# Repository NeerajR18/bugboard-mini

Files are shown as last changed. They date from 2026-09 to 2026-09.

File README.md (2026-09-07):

# bugboard-mini
Small Size development board based on the STM32G431KBT6

## Features
- Small PCB, 20 mm x 25 mm
- Debug headers included
- Supports USART

## PCB

#### Schematic


#### PCB

- PCB front



- PCB back



Made fully in KiCad.

## Bill of Materials

| MPN | Quantity | Unit Price (USD) | Ext. Price (USD) | Link |
|---|---:|---:|---:|---|
| STM32G431KBT6 | 1 | $7.03 | $7.03 | [LionCircuits](https://www.lioncircuits.com/parts/STM32G431KBT6) |
| RC0402FR-1010KL | 100 | $0.0037 | $0.37 | [Robu](https://robu.in/product/rc0402fr-1010kl-yageo-0-063w-thick-film-resistors-%c2%b1100ppm-%e2%84%83-%c2%b11-10k%cf%89-0402-chip-resistor-surface-mount-rohs/) |
| RC0402FR-075K1L | 100 | $0.002 | $0.20 | [Robu](https://robu.in/product/rc0402fr-075k1l-yageo-res-thick-film-0402-5-1k-ohm-1-0-063w1-16w-%c2%b1100ppm-c-pad-smd-t-r/) |
| XC6206P182MR | 5 | $0.037 | $0.185 | [Robu](https://robu.in/product/xc6206p182mr-twgmc-70db1khz-300ma-fixed-1-8v-positive-electrode-6v-sot-23-voltage-regulators-linear-low-drop-out-ldo-regulators-rohs/) |
| TCC0402X5R104K500AT | 100 | $0.0025 | $0.25 | [Robu](https://robu.in/product/tcc0402x5r104k500at-cctc-smt-ceramic-capacitors-0402-x5r-104k100nf%c2%b110-rated-voltage50v-thickness0-50mm-tape/) |
| PRTR5V0U2X | 5 | $0.095 | $0.475 | [Robu](https://robu.in/product/prtr5v0u2x215-nexperia-prtr5v0u2x215-esd-protection-device-tvs-7-5-v-sot-143b-4-pins-5-5-v-prtr5/) |
| TYPE-C-31-M-12 | 2 | $0.40 | $0.80 | [Robu](https://robu.in/product/type-c-31-m-12-hroparts-5a-1-16p-female-type-c-smd-usb-connectors-rohs/) |
| SMD0603P050TF | 5 | $0.13 | $0.65 | [Robu](https://robu.in/product/smd0603p050tf-pttcpolytronics-tech-6v-40a-500ma-1a-0603-resettable-rohs/) |
| TS-1088-AR02016 | 5 | $0.029 | $0.145 | [Robu](https://robu.in/product/1-month-warranty-470/) |
| CC0402MRX5R5BB106 | 10 | $0.048 | $0.48 | [Robu](https://robu.in/product/cc0402mrx5r5bb106-yageo-cap-smd-mlcc-10-%c2%b5f-6-3-v-0402-1005-metric-20-x5r-cc-series/) |
| PCB from ROBU | 5 | $1.90 | $9.52 | [Robu](https://robu.in/product/online-pcb-manufacturing-service/) |
| Shipping Charges | - | $5.00 | $5.00 | - |
| **Total** | | **$14.6772** | | |

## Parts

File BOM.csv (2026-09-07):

MPN | Quantity | Unit Price(USD) | Ext. Price(USD) | Link
STM32G431KBT6 | 1 | 7.03 | 7.03 | https://www.lioncircuits.com/parts/STM32G431KBT6
RC0402FR-1010KL | 100 | 0.0037 | 0.37 | https://robu.in/product/rc0402fr-1010kl-yageo-0-063w-thick-film-resistors-%c2%b1100ppm-%e2%84%83-%c2%b11-10k%cf%89-0402-chip-resistor-surface-mount-rohs/
RC0402FR-075K1L | 100 | 0.002 | 0.2 | https://robu.in/product/rc0402fr-075k1l-yageo-res-thick-film-0402-5-1k-ohm-1-0-063w1-16w-%c2%b1100ppm-c-pad-smd-t-r/
XC6206P182MR | 5 | 0.037 | 0.185 | https://robu.in/product/xc6206p182mr-twgmc-70db1khz-300ma-fixed-1-8v-positive-electrode-6v-sot-23-voltage-regulators-linear-low-drop-out-ldo-regulators-rohs/
TCC0402X5R104K500AT | 100 | 0.0025 | 0.25 | https://robu.in/product/tcc0402x5r104k500at-cctc-smt-ceramic-capacitors-0402-x5r-104k100nf%c2%b110-rated-voltage50v-thickness0-50mm-tape/
PRTR5V0U2X | 5 | 0.095 | 0.475 | https://robu.in/product/prtr5v0u2x215-nexperia-prtr5v0u2x215-esd-protection-device-tvs-7-5-v-sot-143b-4-pins-5-5-v-prtr5/
TYPE-C-31-M-12 | 2 | 0.4 | 0.8 | https://robu.in/product/type-c-31-m-12-hroparts-5a-1-16p-female-type-c-smd-usb-connectors-rohs/
SMD0603P050TF | 5 | 0.13 | 0.65 | https://robu.in/product/smd0603p050tf-pttcpolytronics-tech-6v-40a-500ma-1a-0603-resettable-rohs/
TS-1088-AR02016 | 5 | 0.029 | 0.145 | https://robu.in/product/1-month-warranty-470/
CC0402MRX5R5BB106 | 10 | 0.048 | 0.48 | https://robu.in/product/cc0402mrx5r5bb106-yageo-cap-smd-mlcc-10-%c2%b5f-6-3-v-0402-1005-metric-20-x5r-cc-series/
PCB from ROBU | 5 | 1.9 | 9.52 | https://robu.in/product/online-pcb-manufacturing-service/
Shipping Charges | - | 5 | 5
Total |  | 14.6772

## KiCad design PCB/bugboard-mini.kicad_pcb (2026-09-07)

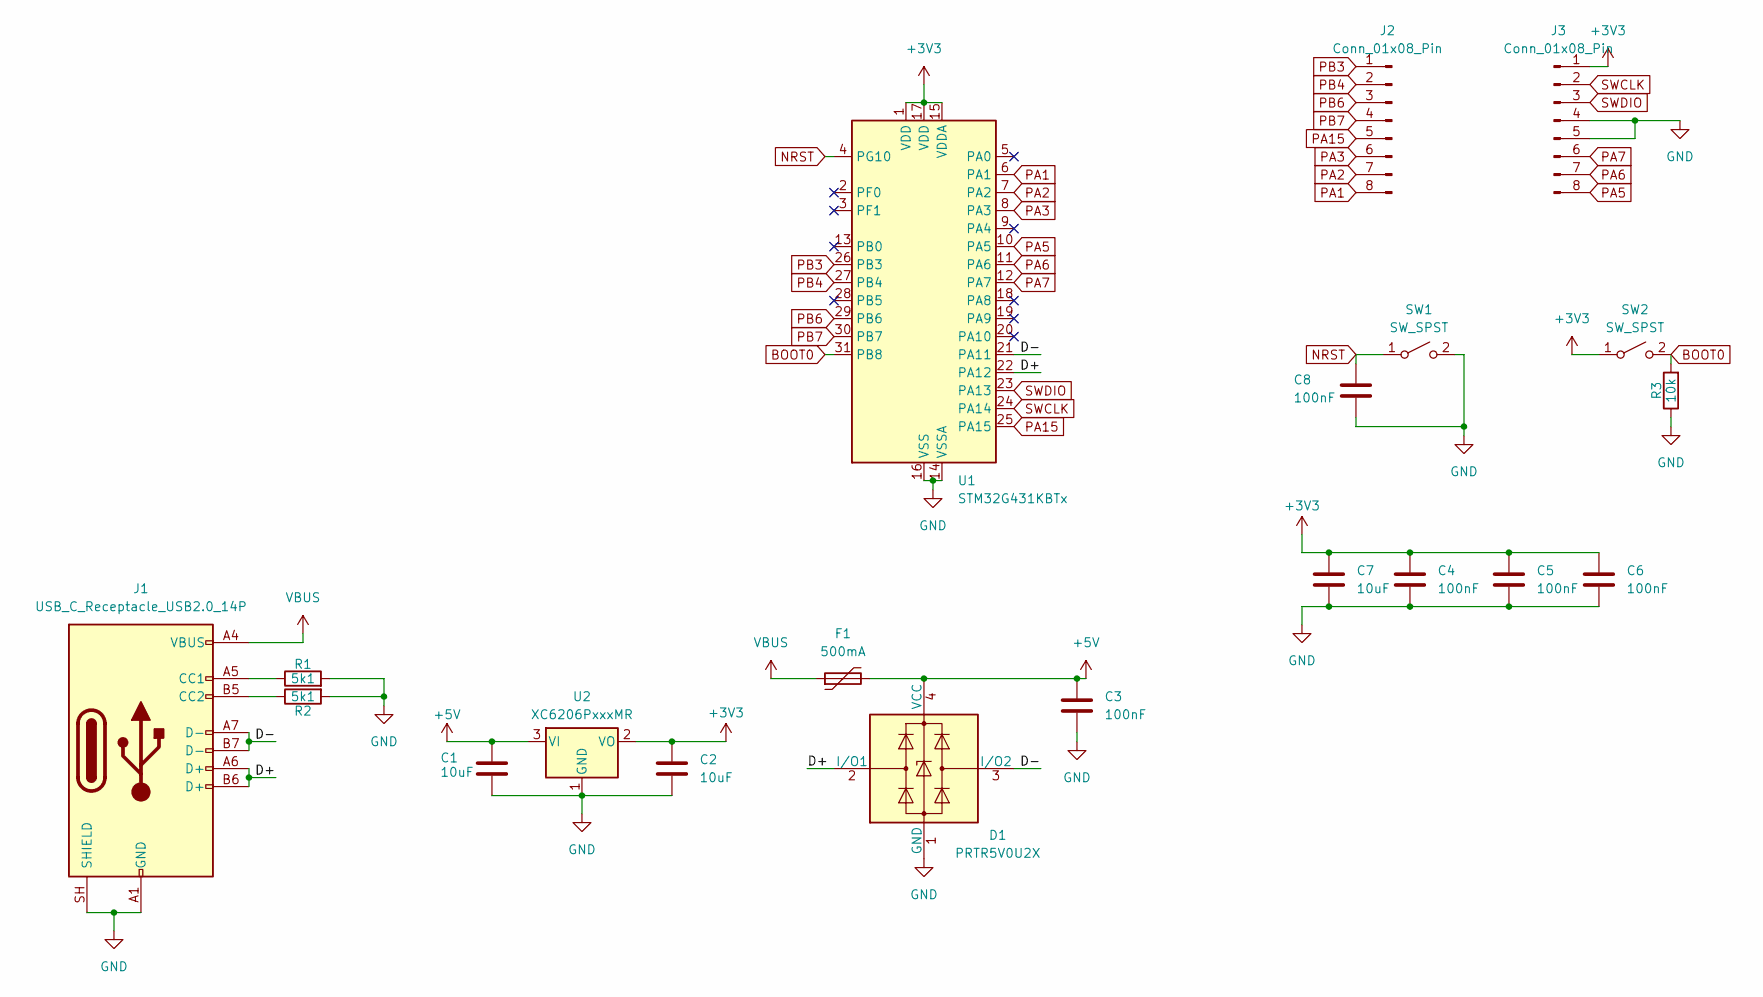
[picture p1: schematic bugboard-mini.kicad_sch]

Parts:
C1, C2, C7: 10uF; C_0402_1005Metric
C3, C4, C5, C6, C8: 100nF; C_0402_1005Metric
D1: PRTR5V0U2X; SOT-143
F1: 500mA; Fuse_0603_1608Metric
J1: USB_C_Receptacle_USB2.0_14P; USB_C_Receptacle_HRO_TYPE-C-31-M-12
J2, J3: Conn_01x08_Pin; PinHeader_1x08_P2.54mm_Vertical
R1, R2: 5k1; C_0402_1005Metric
R3: 10k; C_0402_1005Metric
SW1, SW2: SW_SPST; SW_SPST_TS-1088-xR020
U1: STM32G431KBTx; LQFP-32_7x7mm_P0.8mm
U2: XC6206PxxxMR; SOT-23-3

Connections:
+3V3: C2.1, C4.1, C5.1, C6.1, C7.1, J3.1, SW2.1 (A), U1.1 (VDD), U1.15 (VDDA), U1.17 (VDD), U2.2 (VO)
+5V: C1.1, C3.1, D1.4 (VCC), F1.2, U2.3 (VI)
/D+: D1.2 (I/O1), J1.A6 (D+), J1.B6 (D+), U1.22 (PA12)
/D-: D1.3 (I/O2), J1.A7 (D-), J1.B7 (D-), U1.21 (PA11)
BOOT0: R3.2, SW2.2 (B), U1.31 (PB8)
GND: C1.2, C2.2, C3.2, C4.2, C5.2, C6.2, C7.2, C8.2, D1.1 (GND), J1.A1 (GND), J1.A12 (GND), J1.B1 (GND), J1.B12 (GND), J1.SH (SHIELD), J3.4, J3.5, R1.2, R2.2, R3.1, SW1.2 (B), U1.14 (VSSA), U1.16 (VSS), U1.32 (VSS), U2.1 (GND)
NRST: C8.1, SW1.1 (A), U1.4 (PG10)
unnamed: J1.A5 (CC1), R1.1
unnamed: J1.B5 (CC2), R2.1
PA1: J2.8, U1.6 (PA1)
PA2: J2.7, U1.7 (PA2)
PA3: J2.6, U1.8 (PA3)
PA5: J3.8, U1.10 (PA5)
PA6: J3.7, U1.11 (PA6)
PA7: J3.6, U1.12 (PA7)
PA15: J2.5, U1.25 (PA15)
PB3: J2.1, U1.26 (PB3)
PB4: J2.2, U1.27 (PB4)
PB6: J2.3, U1.29 (PB6)
PB7: J2.4, U1.30 (PB7)
SWCLK: J3.2, U1.24 (PA14)
SWDIO: J3.3, U1.23 (PA13)
VBUS: F1.1, J1.A4 (VBUS), J1.A9 (VBUS), J1.B4 (VBUS), J1.B9 (VBUS)

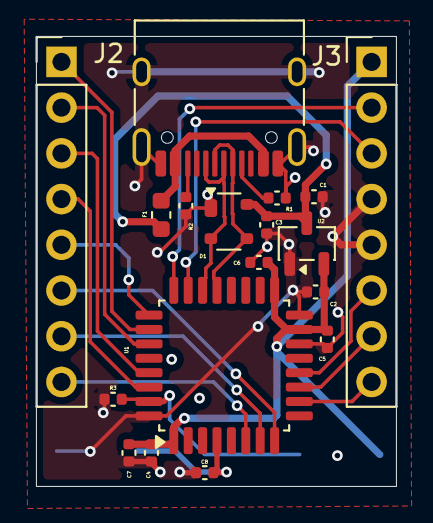
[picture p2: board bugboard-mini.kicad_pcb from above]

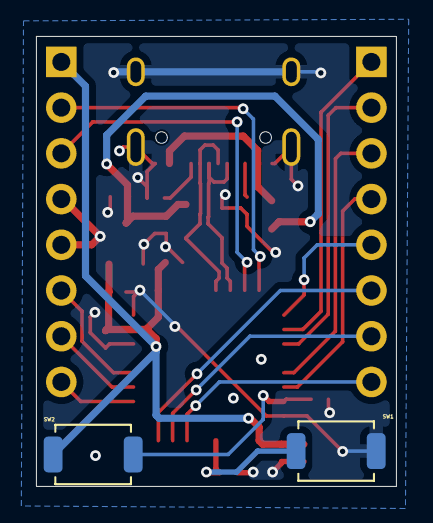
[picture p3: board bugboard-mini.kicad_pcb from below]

Board: 2 copper layers, 20.0 x 25.0 mm, 20 parts (2 on the bottom side), 23 nets.

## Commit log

2026-09-07 Added PCB files
    [bugboard-mini.kicad_pcb, bugboard-mini.kicad_sch]
2026-09-07 Changed directory
    [bugboard-mini.kicad_pcb, bugboard-mini.kicad_sch]
2026-09-07 Added gerbers and BOM
    [BOM.csv]
2026-09-07 update files
    [bugboard-mini.kicad_pcb]
